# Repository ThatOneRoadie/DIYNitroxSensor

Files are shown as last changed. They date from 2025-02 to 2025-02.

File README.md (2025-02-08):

# Notes as of February 8, 2025
Read the readme below carefully as ***this project repo is not complete*** and will not result in a working product if used (yet). I've sent boards off to everyone's favorite PCB fab to be printed, and have yet to edit the models to accommodate the added sensor. The code does work and appears to be stable in "contaminated air" (read: car exhaust) testing. The Oxygen sensor portion was confirmed as accurate against a known-good sensor at my local dive shop.

# DIYNitroxSensor
This is a fork of @rolandoman's fantastic Kitable Nitrox sensor, to add a CO Alarm in the event of contaminated air supply. Given recent dive incidents, a CO Sensor add-in for about $15 (Cheaper than the O2 Sensors too) seems prudent.
Having this kitable for remote sites (bring spare sensors/parts, easy), and keep the project budget low, are the primary goals. Ideally, this entire analyzer would be sub-$50 (USD) completed.

# This is LIFE SUPPORT EQUIPMENT.
As always, once your project is complete, I would ***highly recommend*** you test your sensor against a known-good sensor, e.g. at a local dive store or nitrox fill site with a known-good analyzer. Verify everything works; _your life depends on it_. Analyze your cylinder with more than one sensor, and don't fall victim to confirmation bias (I'm expecting EAN32, my DIY sensor reads 32, perfect let's go diving). Do not dive Enriched Air Nitrox without first taking a course with your local certifying agency regarding the dangers and analysis processes.

# Sources and other information
This project borrows heavily on https://www.divetech.com/post/the-20-nitrox-analyzer (Link is now dead, I'm e-mailing the DiveTech Employee who previously wrote that article), but adds a number of improvements including rechargeable battery circuit, custom PCB, and stronger case.

This repository will mostly contain arduino code files and KiCAD files, plus edits to rolandoman's STL files to house the CO Sensor and slightly different sized PCB.

Rolandoman's main project page for the analyzer **without the CO sensor** can be found on instructables: https://www.instructables.com/Yet-Another-DIY-Nitrox-Sensor/

Rolandoman's 3D printer files, again **without the CO Sensor** can be found on Thingiverse: https://www.thingiverse.com/thing:6300317

This is a diagram of the basic connections for the arduino pro mini below, including the CO Sensor on ADC Pin A2 (only a single pin is needed for the ZE15-CO Package):
Nitrox Board

Here is a picture of the specialized PCB for the project designed on KiCAD. File included in the project.




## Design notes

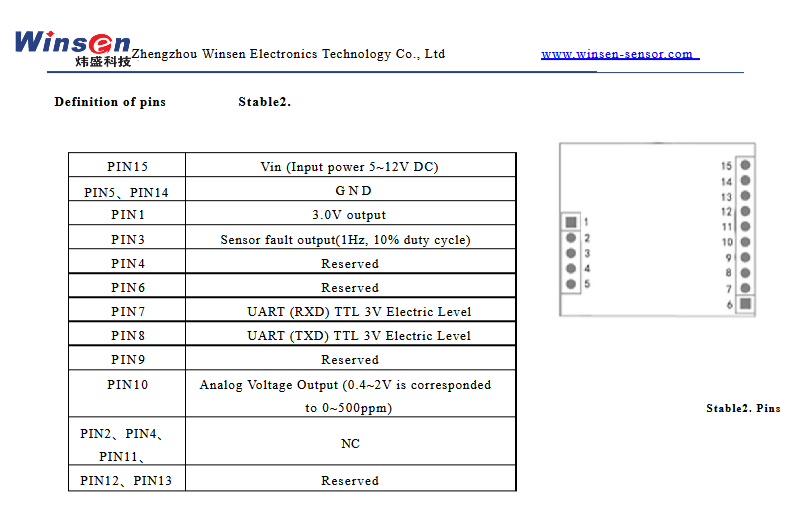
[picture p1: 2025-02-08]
ZE15 Sensor Pinout.png

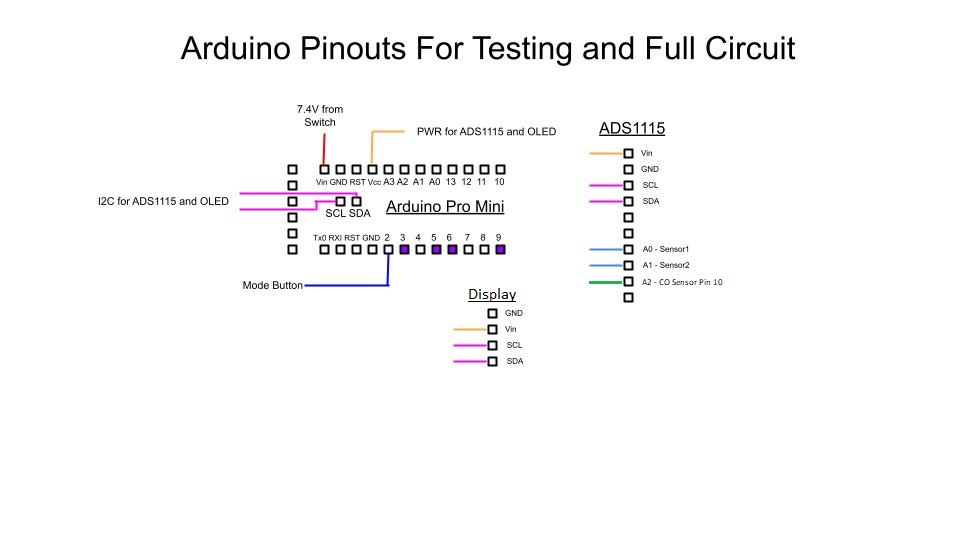
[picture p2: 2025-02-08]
Nitrox Board.jpg

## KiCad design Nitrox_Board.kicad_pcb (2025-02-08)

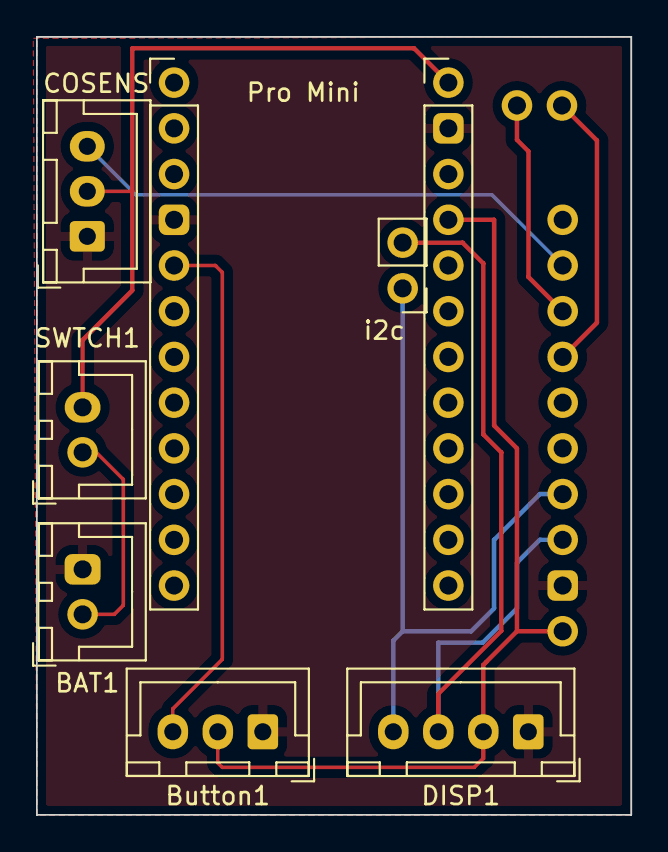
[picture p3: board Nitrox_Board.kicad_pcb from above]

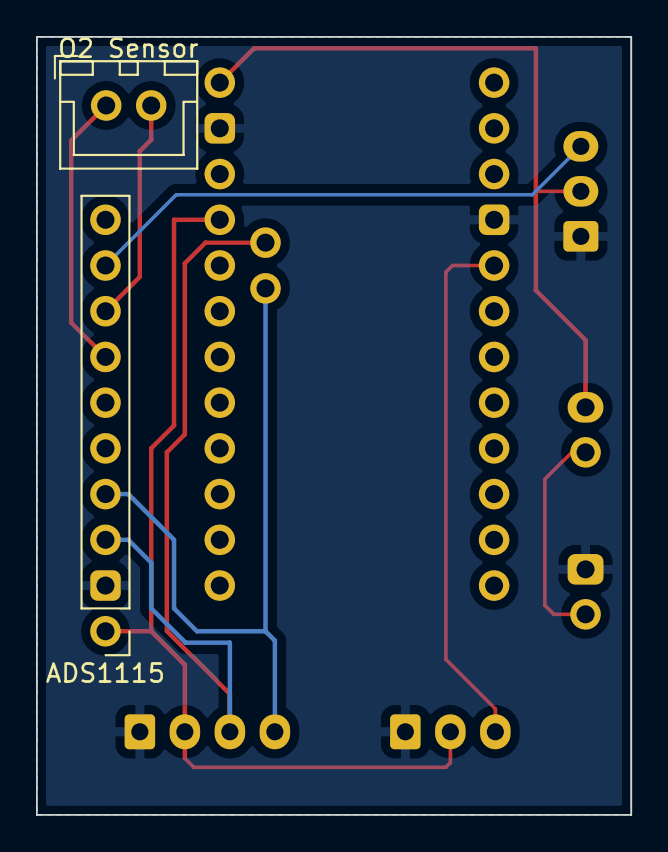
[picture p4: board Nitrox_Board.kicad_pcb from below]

Board: 2 copper layers, 33.0 x 43.2 mm, 10 parts (2 on the bottom side), 9 nets.

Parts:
ADS1115: PinHeader_1x10_P2.54mm_Vertical
BAT1: JST_XH_B2B-XH-A_1x02_P2.50mm_Vertical
Button1: JST_XH_B3B-XH-A_1x03_P2.50mm_Vertical
COSENS: JST_XH_B3B-XH-A_1x03_P2.50mm_Vertical
DISP1: JST_XH_B4B-XH-A_1x04_P2.50mm_Vertical
O2 Sensor: JST_XH_B2B-XH-A_1x02_P2.50mm_Vertical
Pro Mini: PinHeader_1x12_P2.54mm_Vertical
ProMini2: PinHeader_1x12_P2.54mm_Vertical
SWTCH1: JST_XH_B2B-XH-A_1x02_P2.50mm_Vertical
i2c: PinHeader_1x02_P2.54mm_Vertical

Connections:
GND: ADS1115.2, BAT1.2, Button1.1, COSENS.1, DISP1.1, Pro Mini.4, ProMini2.2
unnamed: ADS1115.7, O2 Sensor.1
unnamed: ADS1115.8, O2 Sensor.2
unnamed: BAT1.1, SWTCH1.1
unnamed: Button1.3, Pro Mini.5
unnamed: COSENS.2, ProMini2.1, SWTCH1.2
SCL: ADS1115.3, DISP1.3, i2c.2
SDA: ADS1115.4, DISP1.4, i2c.1
VCC: ADS1115.1, Button1.2, DISP1.2, ProMini2.4

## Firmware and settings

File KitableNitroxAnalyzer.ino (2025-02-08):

/*****************************************************************************
*
* Kitable Nitrox Analyzer for Arduino Pro Mini
* Must alter pins if using any other arduino variant
* 
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
*****************************************************************************/

#include <SPI.h>  // may not be necessary
#include <Wire.h>  // may not be necessary
#include <Adafruit_SSD1306.h>
//#include <Adafruit_ADS1x15.h>
#include "ADS1X15.h"
#include <EEPROM.h>
#include <RunningAverage.h>

#define SCREEN_WIDTH 128 // OLED display width, in pixels
#define SCREEN_HEIGHT 64 // OLED display height, in pixels

#define O2_RA_SIZE 20
#define CO_RA_SIZE 5
RunningAverage RAO2(O2_RA_SIZE);
RunningAverage RACO(CO_RA_SIZE);

ADS1115 ads(0x48); 

#define OLED_RESET 4
Adafruit_SSD1306 display(SCREEN_WIDTH, SCREEN_HEIGHT, &Wire, OLED_RESET);//SCREEN_WIDTH, SCREEN_HEIGHT, &Wire, OLED_RESET

const int buttonPin=2; // push button
const int buzzer = 9; // buzzer
const int ledPin = 13; // led

double calibrationv;
float multiplier;

const int cal_holdTime = 2; // 2 sec button hold to calibration
const int mod_holdTime = 4; // 4 sec hold to po2 mod change
const int max_holdtime = 6; // 6 sec hold to reset max o2 result

long millis_held;    // How long the button was held (milliseconds)
long secs_held;      // How long the button was held (seconds)
long prev_secs_held; // How long the button was held in the previous check
byte previous = HIGH;
unsigned long firstTime; // how long since the button was first pressed 
int active = 0;
double result_max = 0;

/*
 Calculate MOD (Maximum Operating Depth)
*/
float max_po1 = 1.40; //default setting on boot - changed to 1.40 which is more common
const float max_po2 = 1.60;
float cal_mod (float percentage, float ppo2 = 1.4) {
  return 32.8084 * ( (ppo2/(percentage/100)) - 1 );
}

//-----------------------------------------------------------------------------

void beep(int x=1) { // make beep for x time
  //digitalWrite(ledPin, HIGH); // led blink disable for battery save
  for(int i=0; i<x; i++) {    
      tone(buzzer, 2800, 100);
      delay(200);    
  }
  //digitalWrite(ledPin, LOW);
  noTone(buzzer);
}  // end beep function

//-----------------------------------------------------------------------------
//Oxygen Sensor Read
void read_o2_sensor(int adc=0) {  
  int16_t millivolts = 0;
  millivolts = ads.readADC_Differential_0_1();
  RAO2.addValue(millivolts);
}  // end read_o2_sensor function

//CO Sensor Read
void read_co_sensor(int adc=0) {  
  int16_t millivolts = 0;
  millivolts = ads.readADC(2);
  RACO.addValue(millivolts);
}  // end read_co_sensor function
//-----------------------------------------------------------------------------

void setup(void) {  

	Serial.begin(9600);

  /* power saving stuff for battery power */
  // Disable ADC
  // ADCSRA = 0;
  // Disable the analog comparator by setting the ACD bit
  // (bit 7) of the ACSR register to one.
  // ACSR = B10000000;
  // Disable digital input buffers on all analog input pins
  // DIDR0 = DIDR0 | B00111111;

  display.begin(SSD1306_SWITCHCAPVCC, 0x3C);
  
  ads.setGain(2);
  multiplier = 0.0625F;
  ads.begin(); // ads1115 start
  
  pinMode(buttonPin,INPUT_PULLUP);  
  
  RAO2.clear();
  for(int cx=0; cx<= O2_RA_SIZE; cx++) {
     read_o2_sensor(0);
  }
    
  //calibrationv = EEPROMReadInt(0);  
  //if (calibrationv < 1) {
  //  calibrationv = calibrate(0);
  //}

  //Always calibrate on boot
  calibrationv = calibrate(0);
  
  beep(1);
}  // end setup

//-----------------------------------------------------------------------------

void EEPROMWriteInt(int p_address, int p_value)
     {
     byte lowByte = ((p_value >> 0) & 0xFF);
     byte highByte = ((p_value >> 8) & 0xFF);

     EEPROM.write(p_address, lowByte);
     EEPROM.write(p_address + 1, highByte);
     }

//-----------------------------------------------------------------------------

unsigned int EEPROMReadInt(int p_address)
     {
     byte lowByte = EEPROM.read(p_address);
     byte highByte = EEPROM.read(p_address + 1);

     return ((lowByte << 0) & 0xFF) + ((highByte << 8) & 0xFF00);
     }

//-----------------------------------------------------------------------------

int calibrate(int x) {
  
  display.clearDisplay();
  display.setTextColor(WHITE);
  display.setCursor(0,0);  
  display.setTextSize(2);
  display.print(F("Calibrate"));
  display.display();
    
  //RAO2.clear();
  double result;  
  for(int cx=0; cx<= O2_RA_SIZE; cx++) {
    read_o2_sensor(0);
  }
  result = RAO2.getAverage();
  result = abs(result);
  EEPROMWriteInt(x, result); // write to eeprom
  
  // CO.clear();
  double coresult;
  for(int cx=0; cx<= CO_RA_SIZE; cx++) {
    read_co_sensor(0);
  }
  coresult = RACO.getAverage();
  coresult = abs(coresult);
  EEPROMWriteInt(x, coresult); // write to eeprom 

  beep(1);
  delay(1000);
  active = 0;
  return result;
}  // end calibrate function

// Helper to Center Text
void drawCentreString(const String &buf, int x, int y) {
    int16_t x1, y1;
    uint16_t w, h;
    display.getTextBounds(buf, x, y, &x1, &y1, &w, &h); //calc width of new string
    display.setCursor(x - w / 2, y);
    display.print(buf);
}
//-----------------------------------------------------------------------------

void analysing(int x, int cal) {
  double currento2mv=0;
  double currentcomv=0;
  double result;
  double coresult;
  double o2mv = 0.0;
  double comv = 0.0;


  read_o2_sensor(0);
  currento2mv = RAO2.getAverage();
  currento2mv = abs(currento2mv);
  read_co_sensor(0);
  currentcomv = RACO.getAverage();
  currentcomv = abs(currentcomv);  

  
  result = (currento2mv / cal) * 20.9;
  if (result > 99.9) result = 99.9;
  o2mv = currento2mv * multiplier;

  comv = currentcomv * multiplier;
  coresult = (comv - 400) / 8;
  if (coresult < 0) coresult = 0;
  
 
  display.clearDisplay();
  display.setTextColor(WHITE);
  display.setCursor(0,0);
  
  if (o2mv < 0.02 || result <= 0) {
     display.setTextSize(2);
     display.println(F("Sensor"));
     display.print(F("Error!"));
  } else {
    display.setCursor(15,16);
    display.setTextSize(3);
    display.print(result,1);
    display.println(F("%"));

    if (result >= result_max) {
      result_max = result;
    }
    
    display.setTextSize(1);
    display.setCursor(0,3);
    display.setTextColor(BLACK, WHITE);    
    display.print(F("Max "));
    display.print(result_max,1);
    display.print(F("%   "));    
    //display.setCursor(75,31);
    display.print(o2mv,2);    
    display.print(F("mv"));
     
    if (active % 4) {
      display.setCursor(115,29);
      display.setTextColor(WHITE);
      display.print(F("."));
    }  
    
    display.setTextColor(WHITE);
    display.setTextSize(1);
    display.setCursor(0,39);
    display.print(F("pO2 "));
    display.print(max_po1,1);
    display.print(F("  /  "));
    display.print(max_po2,1);
    display.print(F(" MOD"));

    display.setTextSize(1);
    //display.setCursor(0,49);
    //display.print(cal_mod(result_max,max_po1),0);
    //display.print(F("/"));
    //display.print(cal_mod(result_max,max_po2),0);
    //display.print(F("ft "));
    String modstr = String(int(cal_mod(result,max_po1))) + "/" + String(int(cal_mod(result,max_po2))) + " ft";
    drawCentreString(modstr,64,49);

    display.setTextSize(1);
    display.setCursor(0,57);
    display.setTextColor(BLACK, WHITE);    
    display.print(F("CO:"));
    display.print(coresult,1);
    display.print(F(" ppm "));    
    //display.setCursor(75,31);
    display.print(comv,0);    
    display.print(F("mv"));
    
    // menu
    if (secs_held < 7 && active > 16) {
      display.setTextSize(2);
      display.setCursor(0,31);
      display.setTextColor(BLACK, WHITE);      
      if (secs_held >= cal_holdTime && secs_held < mod_holdTime) {
        display.print(F("   CAL    "));
      }
      if (secs_held >= mod_holdTime && secs_held < max_holdtime) {
        display.print(F("   PO2    "));
      }
      if (secs_held >= max_holdtime && secs_held < 10) {
        display.print(F("   MAX    "));
      }     
    }  
    // CO Alarm
    if (coresult > 0){
      if (active % 3) {
        display.setCursor(0,16);
        display.setTextSize(3);
        display.setTextColor(BLACK, WHITE);
        display.println(F("CO WARN"));
        }
    }
  }
  display.display();
}  // end analysing function

//-----------------------------------------------------------------------------

void lock_screen(long pause = 5000) {
  beep(1);
  display.setTextSize(1);
  display.setCursor(0,37);  
  display.setTextColor(0xFFFF, 0);
  display.print(F("                "));
  display.setTextColor(BLACK, WHITE);
  display.setCursor(0,37);
  display.print(F("======= LOCK ======="));
  display.display();
  for (int i = 0; i < pause; ++i) {   
    while (digitalRead(buttonPin) == HIGH) {
      }
   }
   active = 0;
}  // end lock_screen function

//-----------------------------------------------------------------------------

void po2_change() {  
  if (max_po1 == 1.3) max_po1 = 1.4;
  else if (max_po1 == 1.4) max_po1 = 1.5;
  else if (max_po1 == 1.5) max_po1 = 1.3;
  
  display.clearDisplay();
  display.setTextColor(WHITE);
  display.setCursor(0,0);  
  display.setTextSize(2);
  display.println(F("pO2 set"));
  display.print(max_po1);
  display.display();
  beep(1);   
  delay(1000);
  active = 0;  
}  // end po2_change function

//-----------------------------------------------------------------------------

void max_clear() {
  result_max = 0;
  display.clearDisplay();
  display.setTextColor(WHITE);
  display.setCursor(0,0);  
  display.setTextSize(2);
  display.println(F("Max result"));
  display.print(F("cleared"));
  display.display();
  beep(1);   
  delay(1000);
  active = 0;
}  // end max_clear function

//-----------------------------------------------------------------------------

void loop(void) {

  int current = digitalRead(buttonPin);
 
  if (current == LOW && previous == HIGH && (millis() - firstTime) > 200) {
    firstTime = millis();
    active = 17;
  }

  millis_held = (millis() - firstTime);
  secs_held = millis_held / 1000;

  if (millis_held > 2) {
    if (current == HIGH && previous == LOW) {
      if (secs_held <= 0) {
        lock_screen();
      }
      if (secs_held >= cal_holdTime && secs_held < mod_holdTime) {        
        calibrationv = calibrate(0);
      }
      if (secs_held >= mod_holdTime && secs_held < max_holdtime) {
        po2_change();
      }
      if (secs_held >= max_holdtime && secs_held < 12) {
        max_clear();
      }
    }
  }

  previous = current;
  prev_secs_held = secs_held;
  
  analysing(0,calibrationv);
  delay(200);
    
  active++;
}  // end loop function

// End Program

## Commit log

2023-11-08 Update README.md
    PCB imgs
2023-11-09 Delete GerberFiles/Test
    deleted
2025-01-24 Initial Sketch
    Pending some breadboard work, basic diagram and pinouts.
    [Nitrox_Board.kicad_pcb, Nitrox_Board.kicad_sch]
2025-01-26 CO Sensor Changes
    Add CO Sensor Alarm to display render, add CO Sensor to ADC pin 3 (non-diff reading), Add various math/variables for CO Sensor and to differentiate from O2 Sensor, Always calibrate on Boot/Reset, and FREEDOM UNITS (MOD in Feet instead of meters).
    PCB Updated to add CO Sensor leads and LED lead for button illumination when on.
    [Nitrox_Board.kicad_pcb, Nitrox_Board.kicad_sch]
2025-01-26 Delete Nitrox_Board.kicad_prl
    Junk Files
2025-01-26 Delete Nitrox_Board.kicad_pro
    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
2025-02-08 V1.0 PCB iteration
    Final changes to board for CO Sensor after wiring test, send Gerber and drill files to PCBWay.
    [Nitrox_Board-B_Cu.gbr, Nitrox_Board-B_Mask.gbr, Nitrox_Board-B_Paste.gbr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]
2025-02-08 Board Thickness
    Loljk board thickness, now we're final.
    [Nitrox_Board-B_Cu.gbr, Nitrox_Board-B_Mask.gbr, Nitrox_Board-B_Paste.gbr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]
2025-02-08 Update README.md
    Current progress (PCB off to fab), notes.

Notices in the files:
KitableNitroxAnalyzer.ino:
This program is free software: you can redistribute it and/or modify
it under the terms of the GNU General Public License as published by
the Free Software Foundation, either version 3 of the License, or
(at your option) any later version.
